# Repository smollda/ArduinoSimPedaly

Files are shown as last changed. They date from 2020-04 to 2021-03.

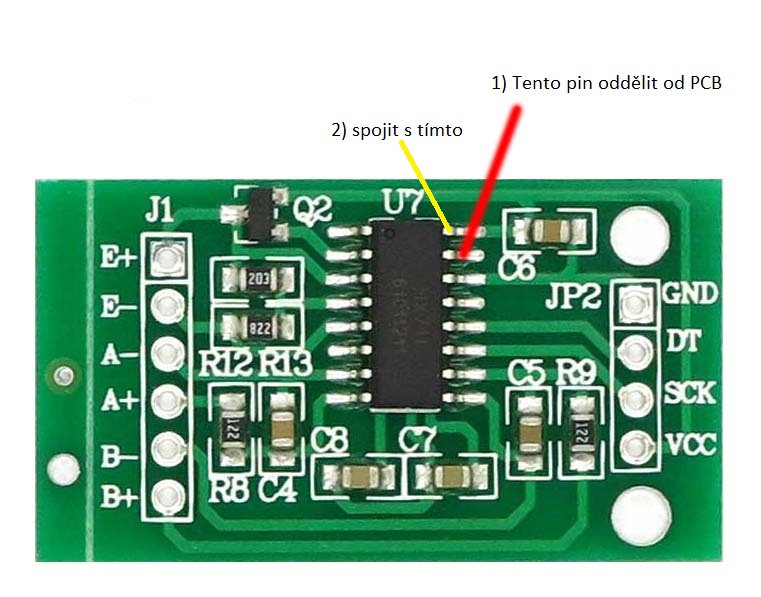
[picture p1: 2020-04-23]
hx711_uprava.jpg

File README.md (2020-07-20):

# ArduinoSimPedaly
Připojení 3 pedálů s použitím loadcellů a 3 modulů HX711

Pozor - pro úspěšné dokončení tohoto projektu je nutné znát základy arduina a celkově programování (po pár tutoriálech na netu podle mně zvládne každý). Zapojit se to dá i pomocí propojovacích kablíků pro nepájivá pole a menší svorkovnice, ale lepší je to připájet alespoň na univerzální plošný spoj - takže pájka, cín a nějaká zkušenost s nimi se taky hodí

V souborech je i můj návrh na plošný spoj tvořený v kicadu (Pedaly.zip) a soubor Pedaly.kicad_pcb, který stačí poslat například sem https://www.plosnaky.cz/ a nechat si ho vyrobit.

V aktuální verzi softwaru mám zakomentován spojkový pedál, protože ho zatím nemám hotový.

Použité knihovny:
HX711 multi https://github.com/compugician/HX711-multi
Arduino Joystick 2.0 https://github.com/MHeironimus/ArduinoJoystickLibrary

# Seznam materiálu:
Arduino Micro / Arduino Leonardo (např. https://www.gme.cz/100-kompatibilni-klon-arduino-micro-atmega32u4-5v)
(pro můj návrh plošného spoje je potřeba konkrétně typ Micro!)

HX711 modul (např. https://www.laskarduino.cz/ad-prevodnik-modul-24-bit-2-kanaly-hx711/)

3x loadcell

V případě osazení na plošný spoj navíc:

Svorkovnice (např. 4x https://www.gme.cz/svorkovnice-ptr-akz700-3-5-08-v-green)

Případně dutinkové lišty - arduino a HX711 moduly se pak nepájí přímo na PCB, ale nacvaknou se do těchto lišt (tohle řešení silně doporučuji!) https://www.gme.cz/dutinkova-lista-bl04g 4x, https://www.gme.cz/dutinkova-lista-bl806g 4x, https://www.gme.cz/dutinkova-lista-bl15g 2x (arduino nemá využity všechny piny, proto stačí 15 pinová dutinková lišta, nebo i kratší

# Zapojení:

Viz Schema.png. Na HX711 modulech je potřeba udělat úpravu pro běh na 80Hz (v základu běží na 10 Hz) - viz hx711_uprava.jpg. Svorkovnice označená jako příprava pro ručku je myšlena pro připojení případného čtvrtého HX711 modulu, umístěného v ruční brzdě - zatím jenom příprava do budoucna. Ve výsledku nejspíš ručku zapojím na separátní arduino třeba s button boxem.

# Program:
Soubor loadcellyHX711.ino obsahuje můj aktuální sketch, který použvám. V podstatě jde jenom o přečtení hodnot ze všech HX711 do pole results[], přepočet těchto hodnot do rozsahu pro knihovnu joystick (v mém sketchi je rozsah špatně, přícházím o přesnost. Správně by na výstup mělo jít číslo mezi -32767 a 32767).

Soubor Pedaly.ino obsahuje novější verzi, kde si arduino samo přepočítá hodnoty vyčtené z HX711 modulů do rozsahu -32767 / 32767. Při prvním spuštění je potřeba provést "kalibraci" - program přečte EEPROM pamět arduina, kde jsou uloženy minimální a maximální hodnoty všech pedálů. Pokud tam tyto hodnoty nejsou (po prvním nahrání tohoto sketche), spustí kalibraci - do konzole vypíše "Start kalibrace" (v tu chvíli je potřeba nechat pedály v základní poloze), dále "Minimální hodnoty: Pedál 1: x, pedál 2: y, pedál 3:z", kde x, y a z jsou hodnoty přečtené z HX711 modulů. Následně se do konzole vypíše "Sešlápni opakovaně všechny 3 pedály na doraz do 10 sekund (brzdu dle libosti)". V tu chvíli je potřeba během následujících 10 sekund sešlápnout všechny 3 pedály, klidně opakovaně. Program uloží maximální hodnoty všech pedálů a použije je pro přepočet hodnot pro výstup na jednotlivé osy (to je ten zmiňovaný rozsah -32767 / 32767). Hodnoty jsou uloženy do paměti EEPROM arduina, zůstanou tedy zachované i po restartu / vypnutí napájení. V některých případech i při přehrání softwaru arduina, tam záleží jak je nastaven bootloader. 

"Kalibraci" pedálů lze znovu provést otevřením konzole v arduino IDE (nástroje -> Seriový monitor) a odesláním znaku "k" (stiskem tlačítka "pošli").

Změna 20.7.2020 - program Pedaly.ino upraven tak, aby neaktualizoval pozici pedálu, pokud přečte z HX711 modulu nesmyslnou hodnotu (extrémně vysoká kladná/záporná hodnota). Použitá knihovna nemá ošetřeno, zda je hodnota přečtená z HX711 modulu platná a jednou za x sekund se stane, že přečte nesmysl - zatím nevím čím je to způsobeno. 
Pokud by náhodou k chybě došlo i během kalibrace, nebude mít pedál správný rozsah - v tom případě stačí kalibraci provést znovu.

Konečnou kalibraci pedálů ve windows (deadzony atd.) lze provést programem DIview stejně jako u Heusinkveld pedálů - viz návod https://www.youtube.com/watch?v=b3Ut4R1O-Sw.

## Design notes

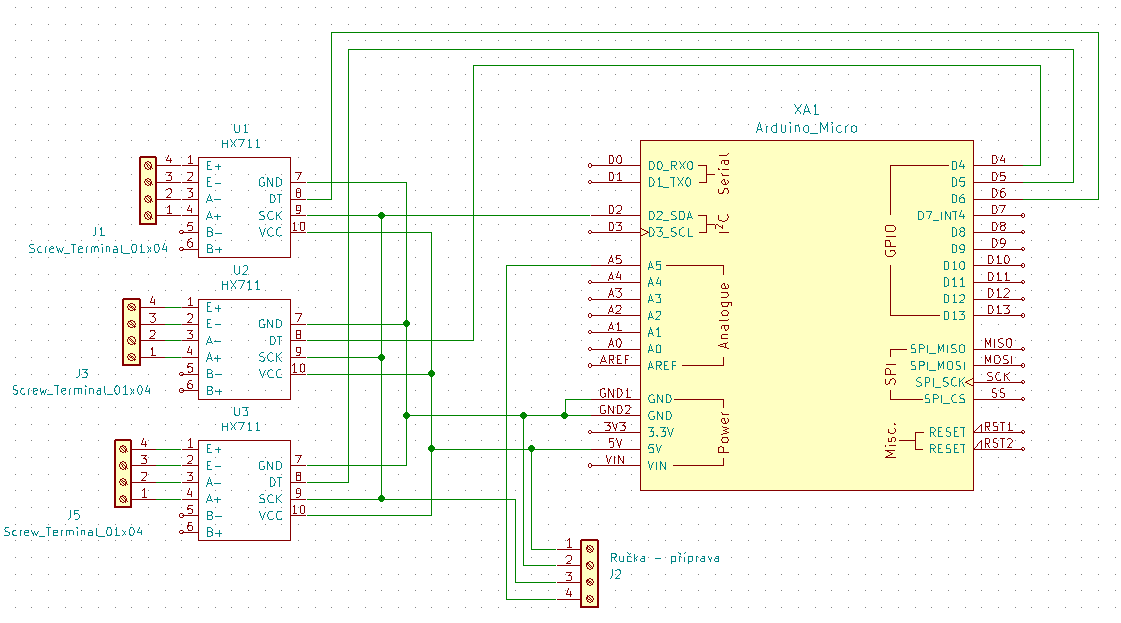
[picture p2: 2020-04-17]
schema.png

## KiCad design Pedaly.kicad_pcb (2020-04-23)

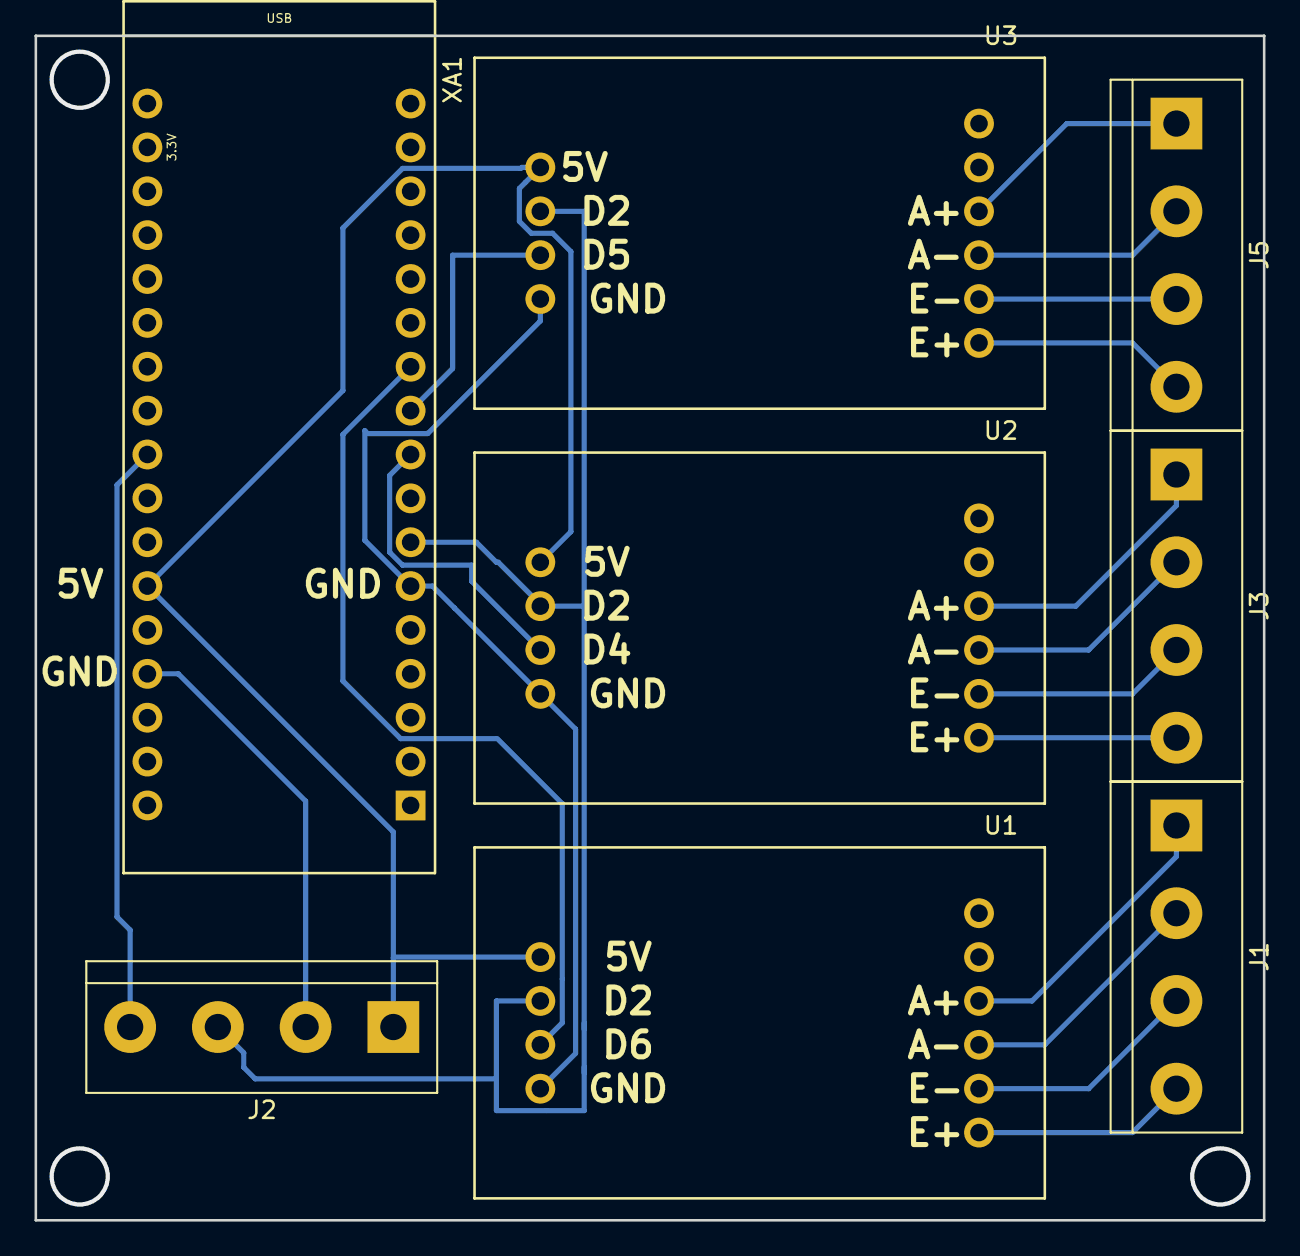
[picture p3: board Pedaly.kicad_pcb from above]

Board: 2 copper layers, 71.1 x 68.6 mm, 8 parts (0 on the bottom side), 19 nets.

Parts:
J1, J3, J5: Screw_Terminal_01x04; TerminalBlock_bornier-4_P5.08mm
J2: Ručka - příprava; TerminalBlock_bornier-4_P5.08mm
U1, U2, U3: HX711
XA1: Arduino_Micro; Arduino_Micro_Socket_uprava

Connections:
unnamed: J1.1, U1.4
unnamed: J1.2, U1.3
unnamed: J1.3, U1.2
unnamed: J1.4, U1.1
unnamed: J2.1, U1.10, U2.10, U3.10, XA1.5V
unnamed: J2.2, U1.7, U2.7, U3.7, XA1.GND1, XA1.GND2
unnamed: J2.3, U1.9, U2.9, U3.9, XA1.D2
unnamed: J2.4, XA1.A5
unnamed: J3.1, U2.4
unnamed: J3.2, U2.3
unnamed: J3.3, U2.2
unnamed: J3.4, U2.1
unnamed: J5.1, U3.4
unnamed: J5.2, U3.3
unnamed: J5.3, U3.2
unnamed: J5.4, U3.1
unnamed: U1.8, XA1.D6
unnamed: U2.8, XA1.D4
unnamed: U3.8, XA1.D5

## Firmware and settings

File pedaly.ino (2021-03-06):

#include "HX711-multi.h"
#include "Joystick.h"
#include <EEPROM.h>
// Definice vstupů pro HX711 moduly
#define CLK 2      // Arduino D2 -> HX711 SCK (všechny tři)
#define DOUT1 4    // Arduino D4 -> HX711 DT (brzda) 
#define DOUT2 5    // Arduino D5 -> HX711 DT (plyn)
#define DOUT3 6   //  Arduino D6 -> HX711 DT (spojka)
#define JOYSTICK_DEFAULT_REPORT_ID 0x04
long pedal1min = 0;
long pedal1max = 0;
long pedal2min = 0;
long pedal2max = 0;
long pedal3min = 0;
long pedal3max = 0;
long kalibraceZacatek;
bool kalibrace = false;
bool kalibraceStart = false;
char recievedChar;
bool newData = false;

byte DOUTS[3] = {DOUT1,DOUT2,DOUT3};
#define CHANNEL_COUNT sizeof(DOUTS)/sizeof(byte)
long int results[CHANNEL_COUNT];

//Definice , zapnutí jednotlivých os / počet tlačítek 
HX711MULTI scales(CHANNEL_COUNT, DOUTS, CLK);
Joystick_ Joystick(JOYSTICK_DEFAULT_REPORT_ID, 
JOYSTICK_TYPE_MULTI_AXIS, 0, 0,
true, true, true, false, false, false,
false, false, false, true, true);

  
void setup() {
  Joystick.begin();
  Serial.begin(115200);
  Serial.println("Setup....");
  Serial.flush();
//  Serial.print("EEprom: ");
//  Serial.println(EEPROMReadlong(0));
  if (EEPROMReadlong(0) == -1)
  {
    
    kalibrace = true;
    kalibraceStart = true;
    kalibraceZacatek = 0;
  }
  else
  {
    pedal1min = EEPROMReadlong(0);
    pedal1max = EEPROMReadlong(4);
    pedal2min = EEPROMReadlong(8);
    pedal2max = EEPROMReadlong(12);
    pedal3min = EEPROMReadlong(16);
    pedal3max = EEPROMReadlong(20);
  }
  
  //Nastavení rozsahu jednotl. os
  Joystick.setXAxisRange(-32767, 32767);
  Joystick.setYAxisRange(-32767, 32767);
  Joystick.setZAxisRange(-32767, 32767);
  Serial.println("program:");
  
}

void loop() {

scales.read(results); // přečtení všech 3 HX711, uložení výsledků do pole results
if (Serial.available() > 0) {
    // read the incoming byte:
    recievedChar = Serial.read();

    // say what you got:
    if (recievedChar == 'k'){
      kalibrace = true;
      kalibraceStart = true;
      kalibraceZacatek = millis();
      Serial.println("Kalibrace:");
      recievedChar = " ";
    }
  }
if (kalibraceStart)
{
  pedal1min = results[0];
  pedal2min = results[1];
  pedal3min = results[2];
  pedal1max = 0;
  pedal2max = 0;
  pedal3max = 0;
  Serial.println("Start kalibrace");
  Serial.print("Minimální hodnoty: Pedál 1:");
  Serial.print(pedal1min);
  Serial.print(" Pedál 2:");
  Serial.print(pedal2min);
  Serial.print(" Pedál 3:");
  Serial.println(pedal3min);
  Serial.println("Sešlápni opakovaně všechny 3 pedály na doraz do 10 sekund (brzdu dle libosti)");
  kalibraceStart = false;
}
if(kalibrace){
  if(results[0] > pedal1max){
    pedal1max = results[0];
  }
  if(results[1] > pedal2max){
    pedal2max = results[1];
  }
  if(results[2] > pedal3max){
    pedal3max = results[2];
  }
}
if (millis() > (kalibraceZacatek + 10000) && kalibrace == true){
  kalibrace = false;
  EEPROMWritelong(0,pedal1min);
  EEPROMWritelong(4,pedal1max);
  EEPROMWritelong(8,pedal2min);
  EEPROMWritelong(12,pedal2max);
  EEPROMWritelong(16,pedal3min);
  EEPROMWritelong(20,pedal3max);
  Serial.println("Konec kalibrace!");
  Serial.print("Maximální hodnoty: Pedál 1:");
  Serial.print(pedal1max);
  Serial.print(" Pedál 2:");
  Serial.print(pedal2max);
  Serial.print(" Pedál 3:");
  Serial.println(pedal3max);
}
if (results[0] >= pedal1min && results[0] <= pedal1max){
Joystick.setXAxis(constrain(prepocet(pedal1min,pedal1max,results[0]),-32767,32767));  // Brzda - 20.7.2020 - přidána kontrola rozsahu - pokud bude hodnota mimo, osa se neaktualizuje
}
if (results[1] >= pedal2min && results[1] <= pedal2max){
Joystick.setYAxis(constrain(prepocet(pedal2min,pedal2max,results[1]),-32767,32767));  // Plyn
}
if (results[2] >= pedal3min && results[2] <= pedal3max){
Joystick.setZAxis(constrain(prepocet(pedal3min,pedal3max,results[2]),-32767,32767));  // Spojka
}

delay(10);  // v příkladu knihovny HX711-multi byl tenhle delay, nevím proč, tak jsem ho tu nechal
}

long EEPROMReadlong(long address) {
  long four = EEPROM.read(address);
  long three = EEPROM.read(address + 1);
  long two = EEPROM.read(address + 2);
  long one = EEPROM.read(address + 3);
 
  return ((four << 0) & 0xFF) + ((three << 8) & 0xFFFF) + ((two << 16) & 0xFFFFFF) + ((one << 24) & 0xFFFFFFFF);
}

void EEPROMWritelong(int address, long value) {
  byte four = (value & 0xFF);
  byte three = ((value >> 8) & 0xFF);
  byte two = ((value >> 16) & 0xFF);
  byte one = ((value >> 24) & 0xFF);
 
  EEPROM.write(address, four);
  EEPROM.write(address + 1, three);
  EEPROM.write(address + 2, two);
  EEPROM.write(address + 3, one);
}

long prepocet (long pedalMin, long pedalMax, long hodnota){
  if((pedalMax - pedalMin)>65535){
    long delitel = (pedalMax-pedalMin)/65535 + 1;
    long offset = pedalMin/delitel + 32767;
    return (hodnota/delitel - offset);
  }
  else {
    long offset = pedalMin + 32767;
    return (hodnota-offset);
  }
  
}

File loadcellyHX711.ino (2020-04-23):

#include "HX711-multi.h"
#include "Joystick.h"

// Pins to the load cell amp
#define CLK 2      // Arduino D2 -> HX711 SCK (všechny tři)
#define DOUT1 4    // Arduino D4 -> HX711 DT (brzda) 
#define DOUT2 5    // Arduino D5 -> HX711 DT (plyn)
#define DOUT3 6   //  Arduino D6 -> HX711 DT (spojka)
#define JOYSTICK_DEFAULT_REPORT_ID 0x04

#define BOOT_MESSAGE "MIT_ML_SCALE V0.8"

#define TARE_TIMEOUT_SECONDS 4

byte DOUTS[3] = {DOUT1,DOUT2,DOUT3};
//byte DOUTS[1] = {DOUT1};
#define CHANNEL_COUNT sizeof(DOUTS)/sizeof(byte)
long int results[CHANNEL_COUNT];

//Definice joysticku, zapnutí jednotlivých os / počet tlačítek (tady 0)
HX711MULTI scales(CHANNEL_COUNT, DOUTS, CLK);
Joystick_ Joystick(JOYSTICK_DEFAULT_REPORT_ID, 
  JOYSTICK_TYPE_MULTI_AXIS, 0, 0,
  true, true, true, false, false, false,
  false, false, false, true, true);

  
void setup() {
  //Serial.begin(115200);
  //Serial.println(BOOT_MESSAGE);
  //Serial.flush();
  Joystick.begin();
  pinMode(11,OUTPUT);
  //Nastavení rozsahu jednotl. os
  Joystick.setXAxisRange(0, 32766);
  Joystick.setYAxisRange(0, 32766);
  Joystick.setZAxisRange(0, 32766);
}

void loop() {
scales.read(results); // přečtení všech 3 HX711, uložení výsledků do pole results
//Serial.println(results[2]/31);
results[1] = results[1] + 20000; // offset pro brzdu aby byla v kladných číslech
if(results[0]>0){         //u mýho loadcellu to občas vyhodí záporný vysoký číslo -65000 nebo tak nějak, proto tenhle if
Joystick.setXAxis(constrain(results[0]/31, 0, 32766));  // Brzda, funkce constrain ořízne číslo aby nebylo menší, než 0 a větší než 32766
//Joystick.setXAxis(16000);

}
Joystick.setYAxis(constrain(results[1]/7, 0, 32766));  // Plyn
//Serial.println(results[1]/7);

//Joystick.setZAxis(constrain(results[2]/7, 0, 32766));  // Spojka
//Serial.println(results[2]/6);

delay(10);  // v příkladu knihovny HX711-multi byl tenhle delay, nevím proč, tak jsem ho tu nechal
}
